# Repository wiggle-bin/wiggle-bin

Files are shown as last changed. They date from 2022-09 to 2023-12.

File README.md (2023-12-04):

# WiggleBin

WiggleBin's mission is to create an **open-source, intelligent vermicomposting bin** that not only nurtures the well-being of worms but also brings joy to their human caretakers.

Currently, our project is in the research and testing phase. To conduct thorough investigations, we have developed the [WiggleR](https://github.com/wiggle-bin/wiggle-r)—an innovative desktop research unit designed for conducting controlled experiments with worms.

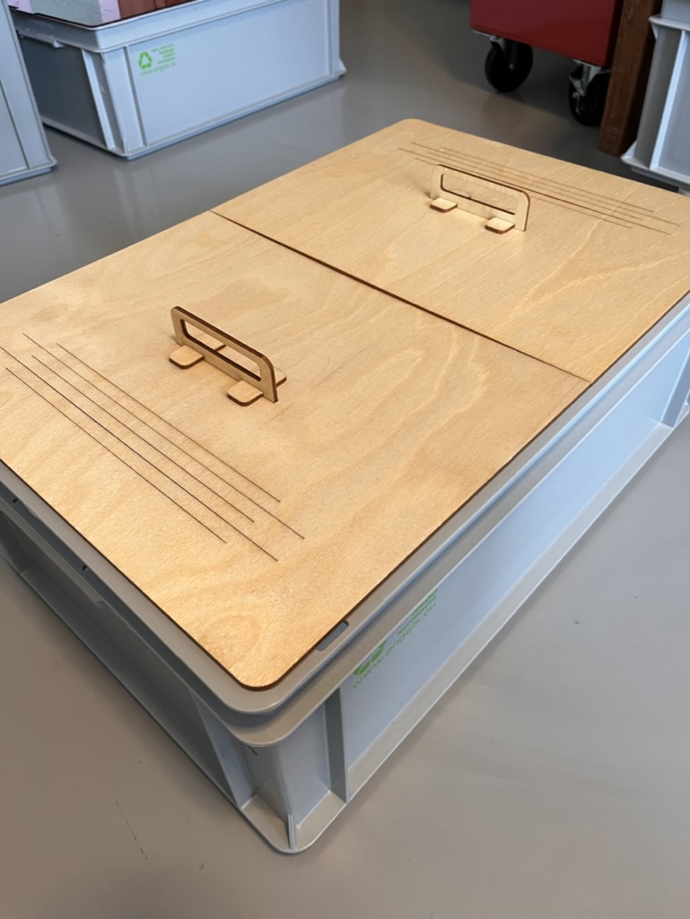
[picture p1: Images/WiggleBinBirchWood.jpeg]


## Why?

Managing a worm bin comes with its share of challenges. Worms may attempt to escape, face risks of overheating, or become too dry. As a caring caretaker, ensuring the well-being of your worms is a priority. The question arises: How can you gauge the happiness of your worms without daily disruptions, constant checks, and the inevitable task of getting your hands dirty?

Here are some of the common problems.
- Overheating
- Drowning
- Too wet
- Too dry
- Lack of oxygen
- Over or under feeding
- Feeding the wrong food

## License

The WiggleBin is open source hardware. Hardware is covered under CERN-OHL-S-2.0 (`LICENSE.CERN-OHL-S-2.0.txt`) license and software under GPL-3.0-or-later (`LICENSE.GPL-3.0-or-later.txt`) license.

## Thanks!

Many thanks to [Open Hardware Academy](https://www.openhardware.academy/01_Welcome.html) and [Stadslab Rotterdam](https://stadslabrotterdam.nl/) for making this build possible.

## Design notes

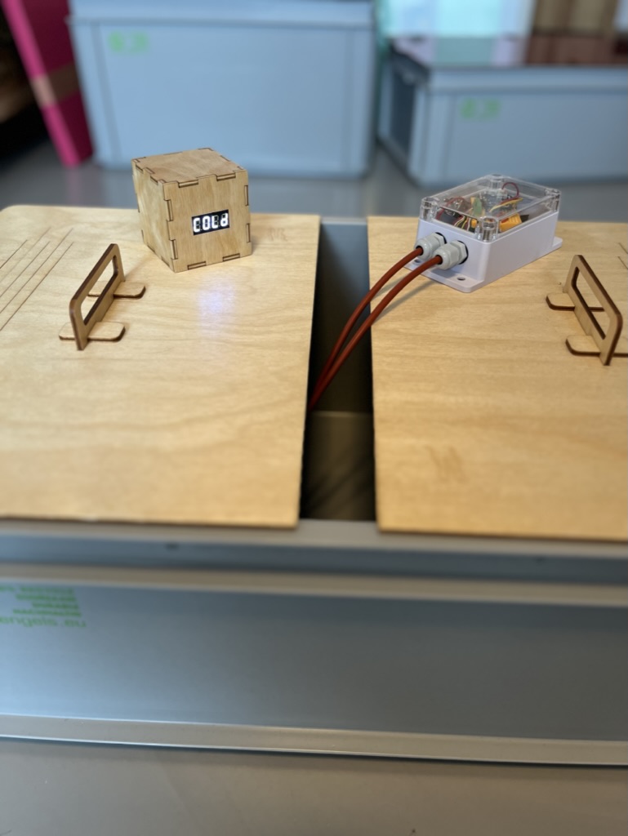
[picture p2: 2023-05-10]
Images/WiggleBinWithAlert.jpeg

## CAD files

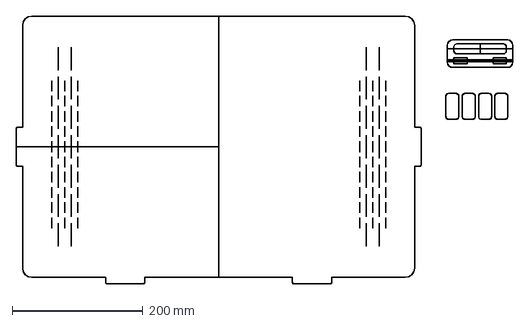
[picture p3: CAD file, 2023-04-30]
Design/LaserCutLidWood1PanelAcrylic3mm.dxf
760.4 x 410.0 mm

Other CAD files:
Design/LaserCutLidWood2Panels.f3d

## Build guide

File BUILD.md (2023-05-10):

# WiggleBin

The following are steps to build our third prototype version WiggleBin V0.0.3.



## Box

### Materials
- Wood or acrylic
- Eurobox
- Oil 

### Tools
- Laser cutter

### Notes

The build for this box is open to variation. The container is a single bin worm bin made from a eurobin. The top has two lids for easy access. 

> When placing the bin inside you might want to tape off the holes with Micropore tape and add clamps to prevent worms crawling out

Vector file for lasercutting can be found in `Design/LaserCutLid`.

The lid has been oiled four times with Danish oil (with 4 hours in between) in the hope to make the Birch wood more durable and stain resistant. The oil can be applied with (paper) cloth. Make sure to read the safety instruction when using oil, since it can be a fire hazard.

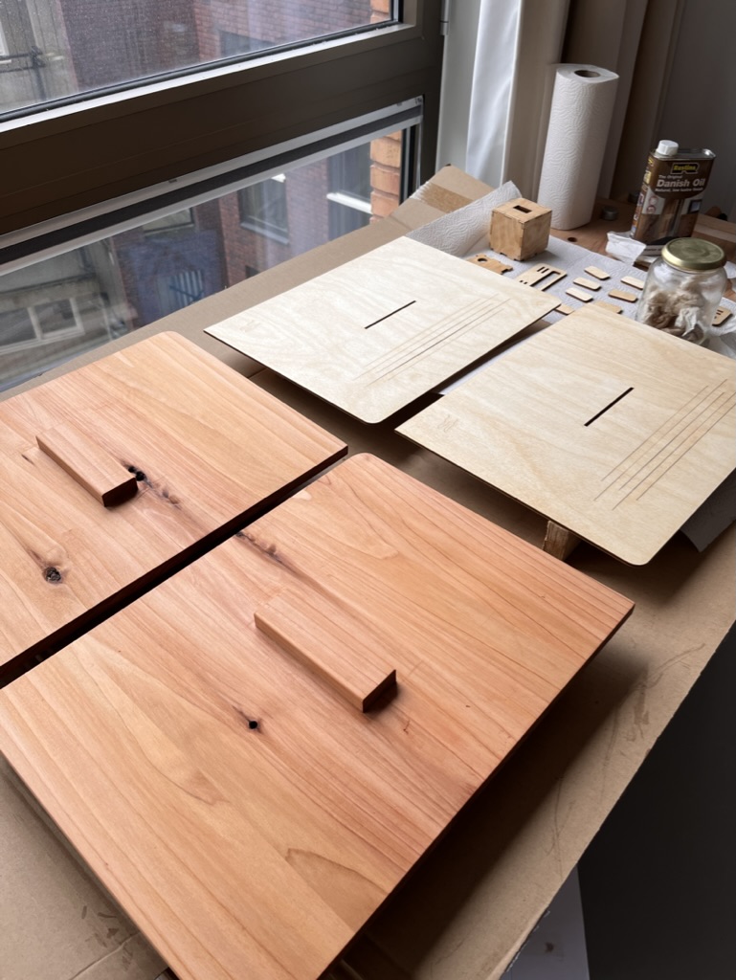
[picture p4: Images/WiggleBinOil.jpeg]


### Improvements

- Using waterproof multiplex
- Enforce lid mid section 
- Air holes should be small strips instead of long stripes
- Connect and lock with square holes available in eurobox
- Make hinge with holes available in eurobox

### Alternatives

We also made some prototypes out of other materials.

*Acrylic*

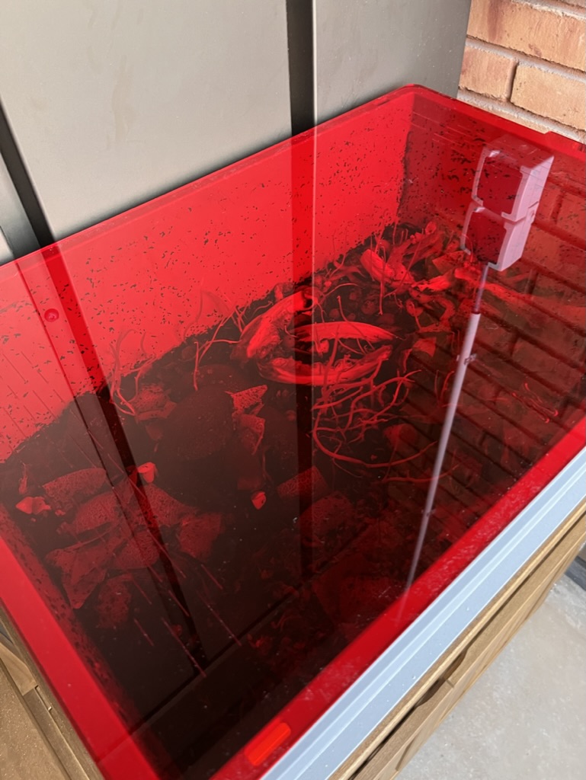
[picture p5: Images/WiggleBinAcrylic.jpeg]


Acrylic has the advantage of being to able to view the inside of the worm bin. The disadvantage is that acrylic traps moist in the worm bin. 

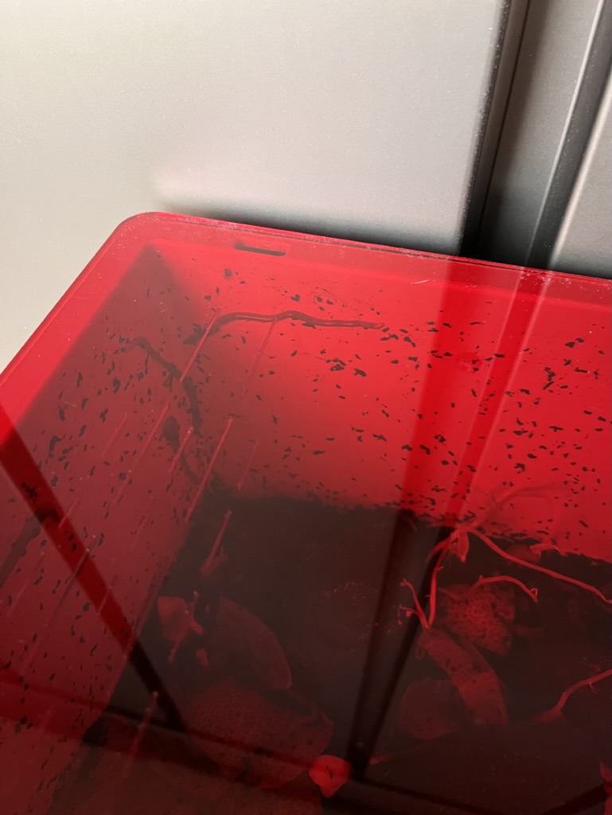
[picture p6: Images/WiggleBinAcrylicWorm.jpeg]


Another interesting side effect is that the tracks of worms on the lid become visible.

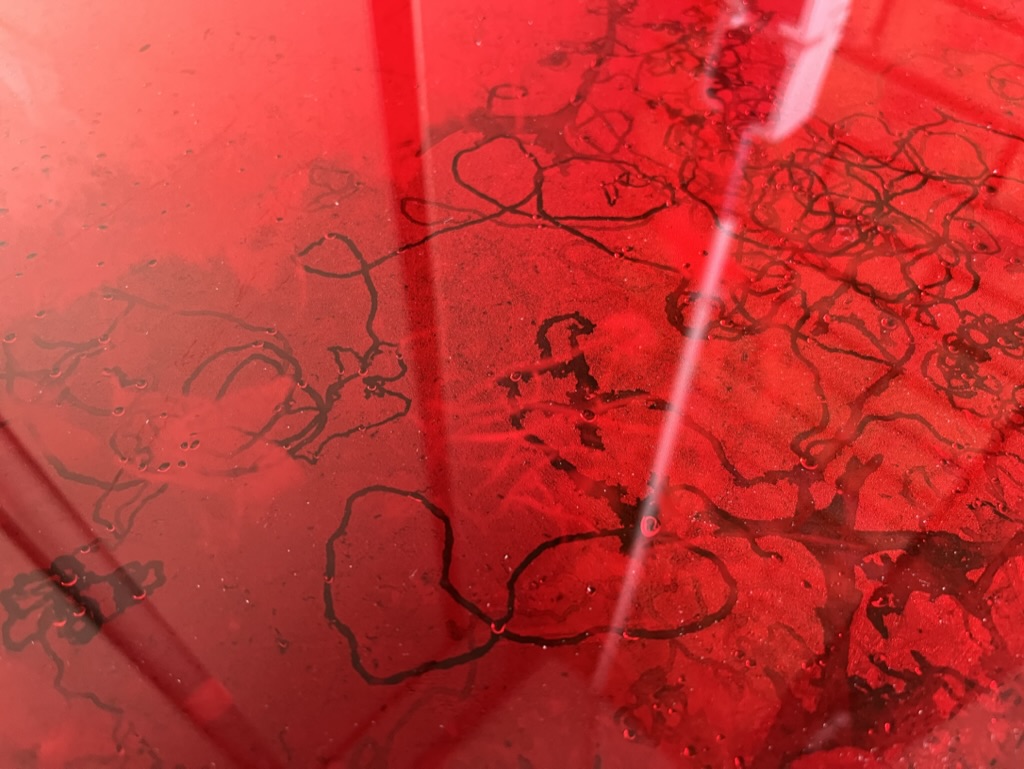
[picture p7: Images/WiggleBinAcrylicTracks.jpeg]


*Cedar wood*

Cedar wood has many properties which make it great for a worm bin. This type of wood is light and durable.

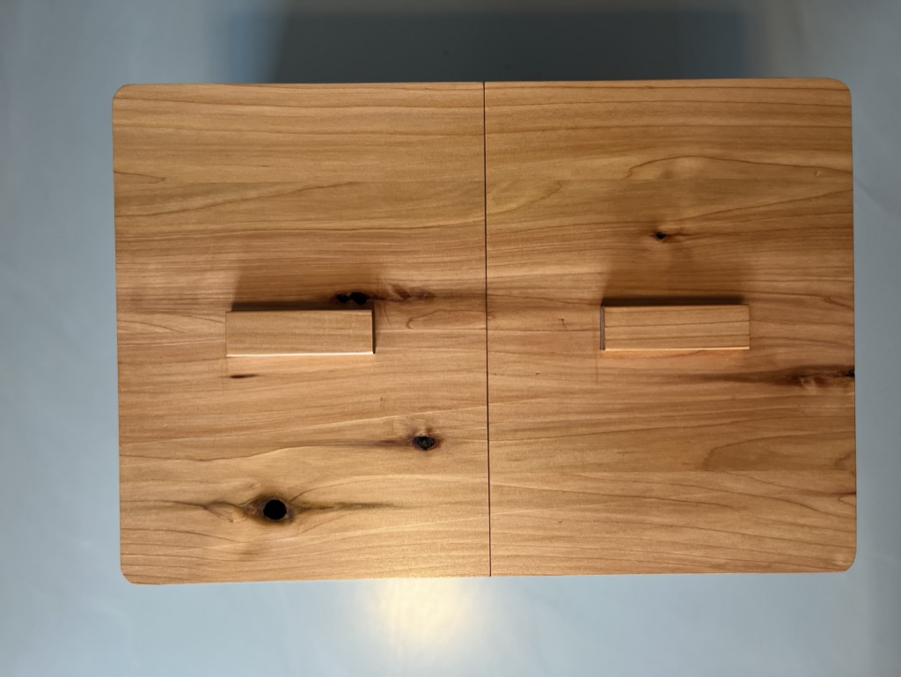
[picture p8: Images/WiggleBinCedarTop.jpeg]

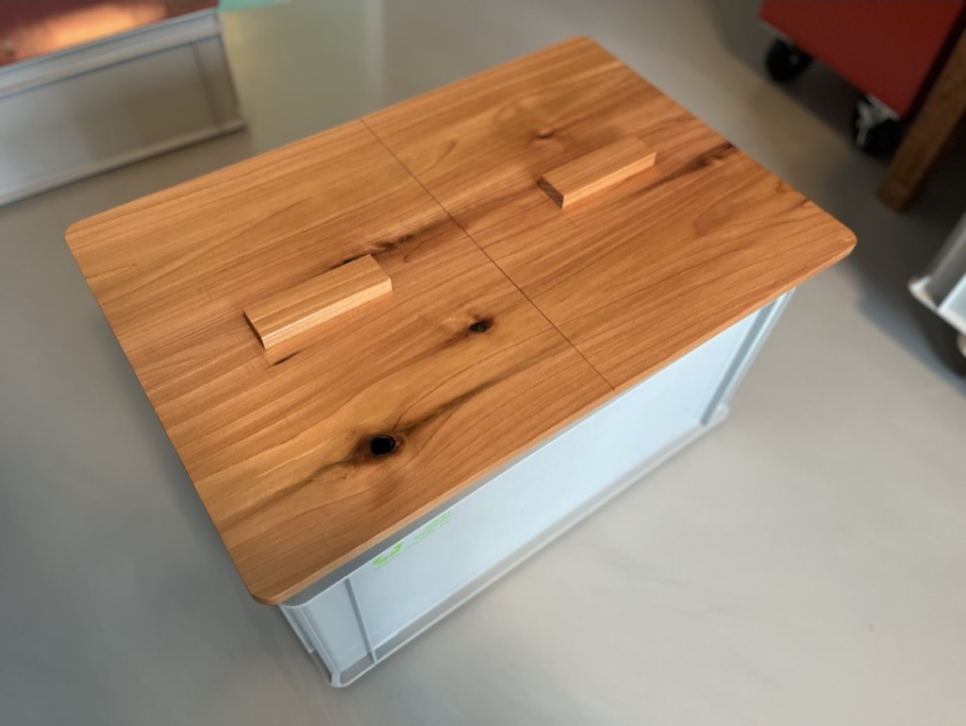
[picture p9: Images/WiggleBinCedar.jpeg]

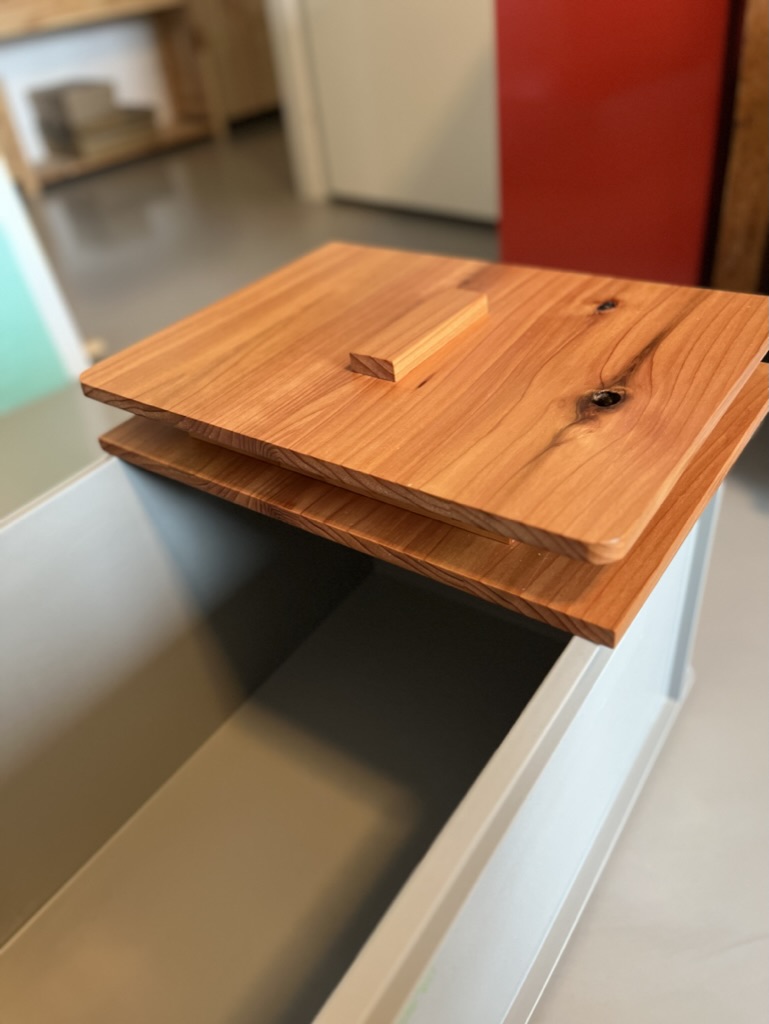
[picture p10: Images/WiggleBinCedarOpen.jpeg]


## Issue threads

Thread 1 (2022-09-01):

Temperature and moist measurements above the soil

studiorabota, 2022-09-01:
Step 1: hypothesis
- We believe that temperature and moist data can be measured without probing the soil
- Hypothesis importance: 2

Step 2: Test
- To verify that, we will place moist and temperature sensors above and in the soil.
- Test cost 2
- Data reliability 1

Step3: Metric
- And measure temperature and moisture data in and above the soil. The data will be collected and analyzed.
- Time required for the build: 10 hours.  To measure: 2 weeks. To analyze 4 hours.

Step 4: Criteria
We are right if the sensors above the soil show a correlation with the sensors in the soil.
met for this test to be positive

Learning documentation

Step 5: Observation
- We observed that .....

Step 6: Learning and insights
- From what we learned that ....

Step 7:
- Therefore, we will ... <what you will do after capturing this insight, perhaps new prototypes or different types of tests>

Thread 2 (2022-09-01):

Feeding worms without opening the bucker

studiorabota, 2022-09-01:
Step 1: hypothesis
- We believe that feeding the worms without opening the bucket should be possible
- Hypothesis importance 1 - major part on how the design and sensors of the bin will be implemented

Step 2: Test
- To verify that, we will create an enclosed bucket with a feeding hole
- Test cost 3 - cheap
- Data reliability 2 - needs to be used for longer period to increase reliability

Step3: Metric
- And measure worms at the start and end. Preferably we also measure with a camera.
- Time required: 5 hours

Step 4: Criteria
We are right if smell and flies are similar or less then a standard bucket and worms have maintained a stable population
met for this test to be positive

Learning documentation

Step 5: Observation
- We observed that .....

Step 6: Learning and insights
- From what we learned that ....

Step 7:
- Therefore, we will ... <what you will do after capturing this insight, perhaps new prototypes or different types of tests>

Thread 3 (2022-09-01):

Camera data will provide valuable input to the user

studiorabota, 2022-09-01:
Step 1: hypothesis
- We believe that camera data will provide valuable input to the user
- Hypothesis importance 1 - can be highly valuable data giving the most accurate data on worm activity

Step 2: Test
- To verify that, we will place a (infrared) camera above the worm bin and take photos each 30 minutes. With additional light which does not affect the worms
- Test cost 2 - Camera will be somewhat expensive, however the setup should straightforward
- Data reliability - 2

Step3: Metric
- And measure how often and how many worms are visible on the photos
- Time required: 4 hours

Step 4: Criteria
We are right if worms are visible in one or more photos

Learning documentation

Step 5: Observation
- We observed that .....

Step 6: Learning and insights
- From what we learned that ....

Step 7:
- Therefore, we will ... <what you will do after capturing this insight, perhaps new prototypes or different types of tests>

studiorabota, 2023-11-18:
Created a timelapse of worm activity. This provided valuable images.

Closed 2023-11-18.

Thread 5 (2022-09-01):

A worm can be detected by microwave sensor

studiorabota, 2022-09-01:
Step 1: hypothesis
- We believe that a worm can be detected by a microwave sensor
- Hypothesis importance - 3 - microwave sensor will probably not provide data which is accurate enough. Upside is that price is cheaper then a camera.

Step 2: Test
- To verify that, we will place a microwave sensor above a bucket with worms
- Test cost 3
- Data reliability 3 - Will only let us know if a microwave sensor picks up a worm, not if the sensor is useful in any way

Step3: Metric
- And measure how often the sensor is triggered
- Time required: 4 hour

Step 4: Criteria
We are right if the sensor is triggered by a worm

Learning documentation

Step 5: Observation
- We observed that .....

Step 6: Learning and insights
- From what we learned that ....

Step 7:
- Therefore, we will ... <what you will do after capturing this insight, perhaps new prototypes or different types of tests>

studiorabota, 2023-11-18:
Tested and no noticeable changes where measured by the microwave sensor when a worm was withing range

Closed 2023-11-18.

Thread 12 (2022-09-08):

Test: Measuring soil (moisture) quality with camera

studiorabota, 2022-09-08:
Test Case Name:
Measuring soil (moisture) quality with camera

Test description:
In this [research](https://www.cell.com/heliyon/fulltext/S2405-8440(21)00183-3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) soil is analyzed with a standard camera and different colored lights (red, blue and green). From the results the wetness/dryness can be obtained. Could a similar setup be interesting for a compost bin?

Revision history:
Created test case 8-9-2022

Function to be tested:
Soil moisture with camera

Environment:
Worm bin with red light (and maybe green and blue)

Test Setup:
Machine learning for image analysis

Test Execution:
Collect image data + data from soil moisture sensor

Expected Results:
Model should be able to differentiate between soil types without getting confused by veggies

Actual Results:
pass / failed

If pass - What actually happens when you run the test?

If failed - put in the description of what you've observed.

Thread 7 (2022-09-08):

Test: Soil moisture sensor data

studiorabota, 2022-09-08:
Test Case Name:
Soil Moisture sensor data test

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

Test description:
Test data returned form Soil moisture sensor V1.2 when placed in wet soil

Revision history:
8-9-2022 : Vincent

Function to be tested:
Data returned from Soil moisture sensor over extended time (couple of days)

Environment:
Small bucket with soil, indoor on desk.

Test Setup:
Computer with Arduino Serial monitor

Test Execution:
1. Fill small bucket with soil
2. Add 1 glass of water
3. Place soil sensor in the soil
4. Manually writing down sensor values

Expected Results:
Return a number which decreases over time as the soil dries out

Actual Results:
✅ pass

If pass - What actually happens when you run the test?
12:53 - 643
13:20 - 664
13:38 - 681
14:52 - 685
15:37 - 691
15:56 - 689
16:30 - 690
17:07 - 687
17:27 - 686
18:52 - 686
20:57 - 681
21:57 - 680
22:07 - 709 - after disconnected
Next day
12:14 - 591

Closed 2023-11-18.

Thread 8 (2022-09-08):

Test: Red light vs. infrared light

studiorabota, 2022-09-08:
Test Case Name:
Red light vs. infrared light

Test description:
The following [research paper](https://www.researchgate.net/figure/Planarian-Photophobic-Responses-Vary-by-Wavelength-A-Images-of-the-photophobia-assay_fig1_269415991) describes the worms reaction to different types of light. For the camera in the worm bin we can use a night vision camera with infrared led light or a standard camera with a red led panel.

Next to the worms reaction we also want to see the difference in image quality between red and infrared light for both machine learning (counting worms) and humans to watch the worms.

Revision history:
Test case created 8-9-2022 - Vincent

Function to be tested:
Worms reaction to infrared and red light

Environment:
Worm bin with red led panel and standard camera + infrared led and night vision camera
Easiest would be a camera which can switch from standard to night vision

Test Setup:
Program to switch between infrared and red light every few hours
Machine learning software to analyze images

Test Execution:
1. Start fresh worm bin
2. Count worms
3. Write down every time worms are getting food
4. Collect images
5. Run in Python algorithm

Expected Results:
Infrared light should attract more worms to the top (on the soil) instead of in the soil
One of the two images provides more accurate worm tracking results

Actual Results:
pass / failed

If pass - What actually happens when you run the test?

If failed - put in the description of what you've observed.

studiorabota, 2023-11-18:
Tested both infrared and red light. Choice is made for an RGB led ring. This enables more functionality such as testing the worms reaction to light.

Closed 2023-11-18.

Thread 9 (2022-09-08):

Test: Worms can be recorded on top of soil

studiorabota, 2022-09-08:
Test Case Name:
Worms can be recorded on top of soil

Test description:
When food is placed in top of the worm bin (without cover like paper and leaves) the worms can filmed processing the food

Revision history:
Test case created 8-9-2022 - Vincent

Function to be tested:
Camera can record worms "eating"

Environment:
Worm bin prototype with transparent viewing window

Test Setup:
Phone with camera
Worm bin with red led panel

Test Execution:
1. Turn on red light
2. Place phone on top of transparent viewing window
3. Record with time-lapse on

Expected Results:
See worms in video

Actual Results:
pass / failed

If pass - What actually happens when you run the test?

If failed - put in the description of what you've observed.

Closed 2023-11-18.

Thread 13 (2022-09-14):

WebThings does not update data

studiorabota, 2022-09-14:
WebThings does not update data from the WiggleBin sensor. This probably has to do with the newly added DeepSleep mode from WebThings. On the address http://xxx.xxx.x.xx/things/WiggleBinSensor/properties we do see the correct values appearing.

studiorabota, 2022-10-05:
Switched to https://www.home-assistant.io/

studiorabota, 2022-10-05:
Switched to https://www.home-assistant.io/

Closed 2022-10-05.

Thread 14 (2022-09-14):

Wemos battery board makes beeping noise when charging batteries

studiorabota, 2022-09-14:

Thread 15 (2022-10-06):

Add red filter to ESP-cam flash light

studiorabota, 2022-10-06:
The ESP-cam needs to be able use the flash, only the worms do not like light. Adding a red filter should solve this issue.

studiorabota, 2022-10-12:
Added red filter as prototype. Have to be tested if this is good enough for worms.

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

studiorabota, 2023-11-18:
Changed to using Raspberry PI with Red light ring

studiorabota, 2023-11-18:
Changed to using Raspberry PI with Red light ring

studiorabota, 2023-11-18:
Changed to using Raspberry PI with Red light ring

studiorabota, 2023-11-18:
Changed to using Raspberry PI with Red light ring

Closed 2023-11-18.

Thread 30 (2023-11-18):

Lasercut elements Friday 24th

studiorabota, 2023-11-18:
- Display bracket
- Air vents
- Breadboard box
- Inner testing boxes
- Soil moisture sensor box

Closed 2023-12-04.

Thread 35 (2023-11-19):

WormGate: Increase marging around holes for top bolts

studiorabota, 2023-11-19:
The lasercutter just managed to cut the hole for the top bolts in the acrylic. Would be good to add some extra margin around the top bolt holes in the middle plates.

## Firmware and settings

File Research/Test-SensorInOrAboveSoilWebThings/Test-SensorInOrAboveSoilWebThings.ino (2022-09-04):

#import "NetworkSettings.h"

// WebThings schema
// https://webthings.io/schemas
// WebThings code bases on
// https://github.com/WebThingsIO/webthing-arduino/blob/master/examples/BME280/BME280.ino

// WebThings
#define LARGE_JSON_BUFFERS 1

#include <Arduino.h>
#include "Thing.h"
#include "WebThingAdapter.h"

const char* ssid = NETWORK_SSID;
const char* password = NETWORK_PASSWORD;

WebThingAdapter *adapter;

const char *helloWormTypes[] = {"TemperatureSensor", nullptr};
ThingDevice helloWorm("HelloWormSensor", "Hello Worm Sensor", helloWormTypes);
ThingProperty helloWormTemperature("temperature", "", NUMBER, "TemperatureProperty");
ThingProperty helloWormHumidity("humidity", "", NUMBER, "HumidityProperty");
ThingProperty helloWormHeatIndex("heat index", "", NUMBER, "TemperatureProperty");
ThingProperty helloWormSoilTemperature("soil temperature", "", NUMBER, "TemperatureProperty");
ThingProperty helloWormSoilMoisture("soil moisture", "", NUMBER, "LevelProperty");
        
// DS18B2 temperature sensor
#include <OneWire.h>
#include <DallasTemperature.h>


// DHT humidity/temperature sensors
#include "DHT.h"


// GPIO where the DS18B20 is connected to
const int oneWireBus = 4;     


// Simple code for Measuring Voltage from
// Capacitive soil moisture sensor
// Check article on how to set AirValue and WaterValue - https://how2electronics.com/capacitive-soil-moisture-sensor-esp8266-esp32-oled-display/
const int AirValue = 860;
const int WaterValue = 440;
int soil_pin = A0; // AOUT pin on sensor
int soilMoisturePercent = 0;


// DHT humidity/temperature sensors
#define DHTPIN D4  


// Uncomment whatever type DHT you are using
//#define DHTTYPE DHT11   // DHT 11
#define DHTTYPE DHT22   // DHT 22  (AM2302)
//#define DHTTYPE DHT21   // DHT 21 (AM2301)


// Setup a oneWire instance to communicate with any OneWire devices
OneWire oneWire(oneWireBus);


// Pass our oneWire reference to Dallas Temperature sensor 
DallasTemperature sensors(&oneWire);


// Initialize DHT sensor.
// Note that older versions of this library took an optional third parameter to
// tweak the timings for faster processors.  This parameter is no longer needed
// as the current DHT reading algorithm adjusts itself to work on faster procs.
DHT dht(DHTPIN, DHTTYPE);


void setup() {
  // Start the Serial Monitor
  Serial.begin(115200);

  // Connect to WIFI
  Serial.println("");
  Serial.print("Connecting to \"");
  Serial.print(ssid);
  Serial.println("\"");
  #if defined(ESP8266) || defined(ESP32)
    WiFi.mode(WIFI_STA);
  #endif
  WiFi.begin(ssid, password);
  Serial.println("");

  // Wait for connection
  while (WiFi.status() != WL_CONNECTED) {
    delay(500);
    Serial.print(".");
  }

  Serial.println("");
  Serial.print("Connected to ");
  Serial.println(ssid);
  Serial.print("IP address: ");
  Serial.println(WiFi.localIP());
  adapter = new WebThingAdapter("w25", WiFi.localIP());

// Set unit for temperature
  helloWormTemperature.unit = "degree celsius";
  helloWormHeatIndex.unit = "degree celsius";
  helloWormSoilTemperature.unit = "degree celsius";

  // Set title to "Pressure"
  helloWormSoilTemperature.title = "Soil Temperature";
  
  // Set title to "Humidity"
  helloWormHumidity.title = "Humidity";
  // Set unit for humidity to %
  helloWormHumidity.unit = "percent";
  // Set humidity as read only
  helloWormHumidity.readOnly = "true";

  // Set title to "Soil Moisture"
  helloWormSoilMoisture.title = "Soil Moisture";
  // Set unit for humidity to %
  helloWormSoilMoisture.unit = "percent";
  // Set humidity as read only
  helloWormSoilMoisture.readOnly = "true";
  // Set min and max for LevelProperty
  helloWormSoilMoisture.minimum = 0;
  helloWormSoilMoisture.maximum = 100;

  // Set title to "Heat Index"
  helloWormHeatIndex.title = "Heat Index";

  helloWorm.addProperty(&helloWormTemperature);
  helloWorm.addProperty(&helloWormHumidity);
  helloWorm.addProperty(&helloWormHeatIndex);
  helloWorm.addProperty(&helloWormSoilTemperature);
  helloWorm.addProperty(&helloWormSoilMoisture);
 
  adapter->addDevice(&helloWorm);
  adapter->begin();

  Serial.println("HTTP server started");
  Serial.print("http://");
  Serial.print(WiFi.localIP());
  Serial.print("/things/");
  Serial.println(helloWorm.id);
  
  // set the analog reference to 3.3V
  analogReference(EXTERNAL); 

  // Start the DS18B20 sensor
  sensors.begin();

  // Start the DHT sensor
  dht.begin();

  //// GATHERING AND SENDING INFORMATION
  
   // WebThings
  ThingPropertyValue value;
  
  // Temperature
  sensors.requestTemperatures(); 
  // Use getTempFByIndex to het Fahrenheit
  value.number = sensors.getTempCByIndex(0);
  helloWormSoilTemperature.setValue(value);

  // Soil Moisture  
  soilMoisturePercent = map(analogRead(soil_pin), AirValue, WaterValue, 0, 100);
  if(soilMoisturePercent > 100) {
    soilMoisturePercent = 100;
  } else if(soilMoisturePercent < 0) {
    soilMoisturePercent = 0;
  }
  value.number = soilMoisturePercent;
  helloWormSoilMoisture.setValue(value);
  
  // DHT Sensor
  // Reading temperature or humidity takes about 250 milliseconds!
  // Sensor readings may also be up to 2 seconds 'old' (its a very slow sensor)
  float h = dht.readHumidity();
  // Read temperature as Celsius (the default), use dht.readTemperature(true) for Fahrenheit
  float t = dht.readTemperature();

  value.number = t;
  helloWormTemperature.setValue(value);
  value.number = h;
  helloWormHumidity.setValue(value);
  value.number = dht.computeHeatIndex(t, h, false);
  helloWormHeatIndex.setValue(value);

  // Send update
  adapter->update();

  Serial.println("Update send to WebThings");
  
  delay(500);

  Serial.println("Deep Sleep");
  ESP.deepSleep(1*60*1000000); // 1 minute sleep
}


void loop() {
 
}

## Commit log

2022-08-20 Added sesnors for soil temperature and moisture
2022-08-20 Added note on buying the right Capacitive Soil Moisture sensor
2022-08-20 Corrected percentage soil moisture
    [Test-SensorInOrAboveSoilWebThings.ino]
2022-09-04 Added links on camera and batteries research
2022-09-04 Added info on red LED panel
2022-09-04 Added info on casing soil moisture sensor
2022-09-04 Added link on powerbank DIY tutorial
2022-09-08 Added links on waterproofing Soil Moisture Sensor
2022-09-08 Added some links on red led lights
2022-09-14 Added documentation on setting up WebThings with the WiggleBin sensor
2022-09-14 Changed the text about connecting the sensors
2022-09-14 Added docs on waterproofing the soil sensor
2022-09-14 Added 3D files for soil sensor film bottle cap and battery holder
    [BatteryHolder.3mf, BatteryHolder.stl, SoilSensorWaterProofCap.3mf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]
2022-09-14 Added info on jamming the soil sensor into the cap
2022-09-14 Added f3d files
    [BatteryHolder.f3d, SoilSensorWaterProofCap.f3d]
2023-01-22 Added code WiggleBinCentral to receive data from I2C devices
2023-01-22 Added code for WiggleBinSoilSensor to measure moist and temperature of soil and send via I2C
2023-02-01 Added I2C Soil Sensor and Light unit
    [WiggleBinLight.fzz]
2023-02-01 Added Fritzing diagram for WiggleBin Soil Sensor
    [HelloWorm.fzz, WiggleBinSoilSensor.fzz]
2023-02-01 Added info on WiggleBin Air Sensor
2023-02-01 Added 3D files for hinges
    [Hinges.3mf, Hinges.f3d, Hinges.stl]
2023-02-01 Added EspHome config for BME680 sensor
2023-02-02 Moved Arduino specific code to Arduino folder in Code
2023-02-02 Removed delay - causing issues in timing of I2C communication
2023-02-02 Send both temp and moist value from Soil Sensor component
2023-02-03 Placed voltage to percentage calculation in EspHome YAML - easier to calibrate
2023-02-09 Changed default build for electronics to not use Attiny I2C components but a Rapsberry Pico W
    [WiggleBinLight.fzz, WiggleBinLightI2C.fzz, WiggleBinSoilSensor.fzz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]
2023-02-09 Added pinout tables from Pico to sensors
2023-02-09 Added images of WiggleBin prototype 0.02 and 3D file for PicoHolder
    [Hinges.3mf, Hinges.f3d, Hinges.stl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]
2023-04-18 Send sensor data via ESP_NOW and MQTT
2023-04-19 Added soilMoisture sensor to EspNow code
2023-04-24 Added version of ESPNow Sender for ESP 32-C board
2023-04-24 Lasercut file for digital display
    [DigitLedDisplayBox.dxf]
2023-04-24 Lasercut file for wormbin lid
    [LaserCutLid.dxf, LaserCutLid.f3d]
2023-04-30 Designs for lasercutting Lid and CameraBox
    [DigitLedDisplayBox.dxf, DigitLedDisplayBox4mm.dxf, LaserCutLid.dxf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]
2023-05-01 WoodCut file for Camera Box
2023-05-03 Changed value to work with ESP32 when moisture sensor is dry
2023-05-03 Added deep sleep to work longer on battery
2023-05-10 Calibrated water value
2023-05-10 Refactor folder structure into 3 sub-projects
    [BatteryHolder.3mf, BatteryHolder.f3d, BatteryHolder.stl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]
2023-05-10 Added code and instructions for setting up soil moisture sensor
2023-05-26 Shell script for recoring audio on Raspberry
2023-05-26 Moved camera shell script to DetectWorms folder
2023-05-26 Renamed DetectWorms folder to Camera
2023-12-04 Moved WiggleR and WiggleAlert out of WiggleBin repo
    [BatteryHolder.3mf, BatteryHolder.f3d, BatteryHolder.stl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]
